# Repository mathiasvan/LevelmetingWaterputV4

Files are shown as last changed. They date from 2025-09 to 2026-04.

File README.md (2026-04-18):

# Levelmeting Waterput V4

## Description

This project is V4 in the levelmeting waterput project. It uses the [QDY30A level sensor with RS485 protocol](https://nl.aliexpress.com/item/1005004940352922.html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) because all the previous sensors broke.

This project uses the [ModbusMaster library](https://github.com/4-20ma/ModbusMaster/tree/master) which can be installed from the Library Manager in the Arduino IDE.

## Components

- Sensor is the [QDY30A level sensor with RS485 protocol](https://nl.aliexpress.com/item/1005004940352922.html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).
- [MAX485 module](https://nl.aliexpress.com/item/1005009235324836.html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) so that the Arduino/ESP32 can communicate with the modbus protocol by using the RX and TX pins.
- AZDelivery ESP32 Dev Kit C V4 for wireless data transmission which I had lying around.
- [220-240V to 24V power adapter](https://www.amazon.com.be/-/en/Universal-Adapter-220-240V-Inverter-Converter/dp/B0DRP7CS6Y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) as the sensor works on 24V.
- [24V to 5V step-down converter](https://www.amazon.com.be/-/en/Heemol-Converter-Module-DC-DC-Power/dp/B0BCV6GRH5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) to power the ESP32. The MAX485 module is powered by the 5V pin of the ESP32.

## Diagram

Thanks lejmr for this diagram. I used it to test my sensor. It is wrong for the TX and RX pins, they should be swapped. (See below for more.) The rest is the same as in this diagram.
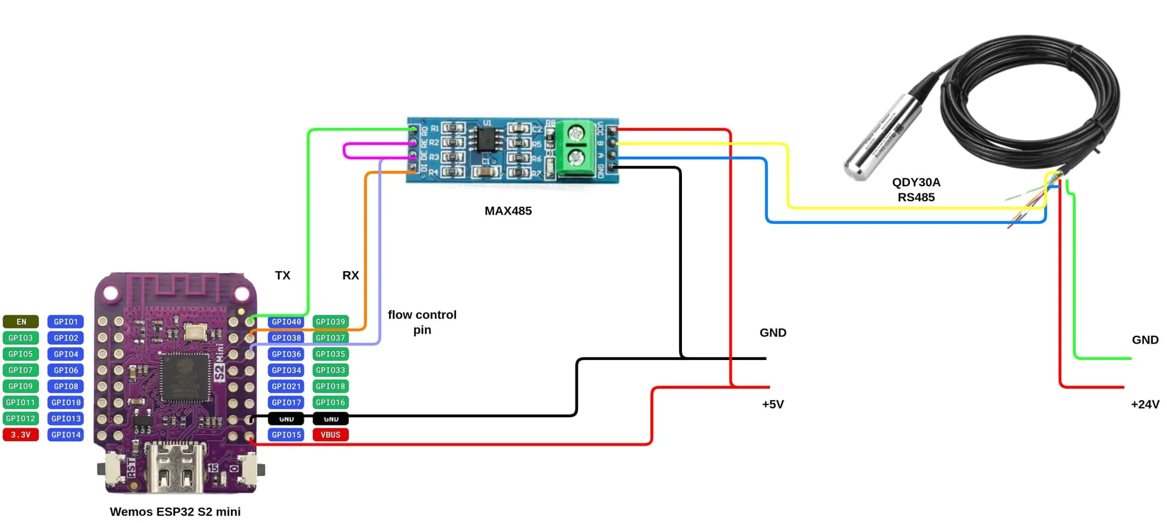
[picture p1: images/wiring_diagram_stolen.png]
Wiring diagram


My adaptation:
I used pin 2 on the ESP32 to connect the DE and RE pins from the MAX485 module.

See the final KiCad diagram under the `waterputv4Schematics` folder. Here is a screenshot in case you don't have KiCad.
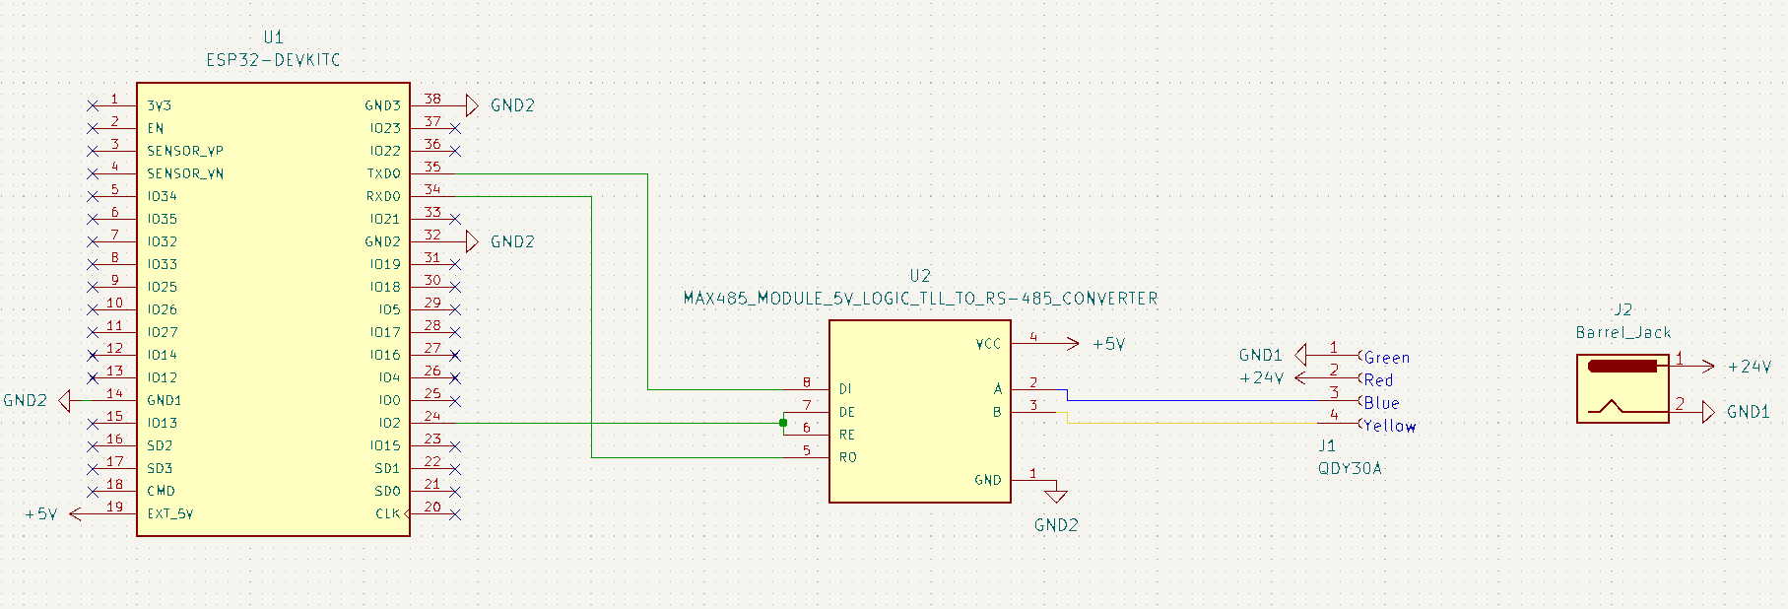
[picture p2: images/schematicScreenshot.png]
The final diagram


## Testing the sensor

This took a lot of trial and error but I got it working in the end. Some important remarks:

1. R0 from the MAX485 module should be connected to RX on the ESP32 and DI to TX. This is wrong in the original diagram I used.
2. The provided screw terminals on the MAX485 module are useful to connect the sensor to.
3. You cannot use the Serial port for debugging as you need the TX and RX pins to communicate with the sensor. I used the Bluetooth Serial library instead. You need to download the Bluetooth Serial app on your phone to connect to the wireless Serial.
4. When uploading the code, disconnect TX, RX, 5V and GND from the MAX485 and ESP32.
5. The test code is in the folder `testcode`.

## Final integration

- I have been using ThingSpeak for all the previous versions and it works quite well to store the data.
- The Bluetooth Serial library took too much space, so I have switched to the TelnetStream library. You need to install PuTTY and enter the IP adress which can be obtained from the Serial monitor. After this, it connects to the modbus sensor and from that moment on, all logging will happen with the telnet stream on PuTTY.
- You need to add a `credentials.h` file in the same folder as the final code. You need to fill this template with your own credentials.

```c++
#define mySSID "xxxxx"
#define myPASSWORD "xxxxx"
#define myChannelNumber 111111
#define myWriteAPIKey "xxxxxx"
```

## Telnet Commands

After connecting to your ESP32 using PuTTY (see IP address in Serial Monitor), you can use the following commands in the telnet console:

- **ping**  
  The ESP32 will respond with `pong`, show the current sensor height, and display the time remaining until the next automatic data upload to ThingSpeak.

- **send data**  
  Immediately triggers a sensor reading and uploads the value to ThingSpeak, regardless of the regular upload interval.

**Example session:**

```
> ping
pong
Doing a height reading...
Data at adress 4: 158
Converted height: 15.8cm
15.80
Time to next data send: 122 seconds

> send data
Sending data now...
Data at adress 4: 158
Converted height: 15.8cm
Height: 15.8cm
Uploading data to ThingSpeak...
Successful upload to ThingSpeak.
Height: 15.80 uploaded to ThingSpeak server.

```

If you enter an unknown command, nothing will happen. Commands are case-sensitive.

**Tip:**  
Make sure you have connected to the correct IP address and that your ESP32 is powered and connected to WiFi.

## Wishlist

- [ ] Add `reconnect wifi` command.
- [ ] OTA updates

## Resources

- [Datasheets that came in the box](https://h5.hlcode.com.cn/?id=NK1LFtJ&f=wx)
- [Thanks a lot to lejmr for this project!](https://github.com/lejmr/dyi-ha-water-management)
- [This tutorial has helped me a lot](https://how2electronics.com/how-to-use-modbus-rtu-with-esp32-to-read-sensor-data/)

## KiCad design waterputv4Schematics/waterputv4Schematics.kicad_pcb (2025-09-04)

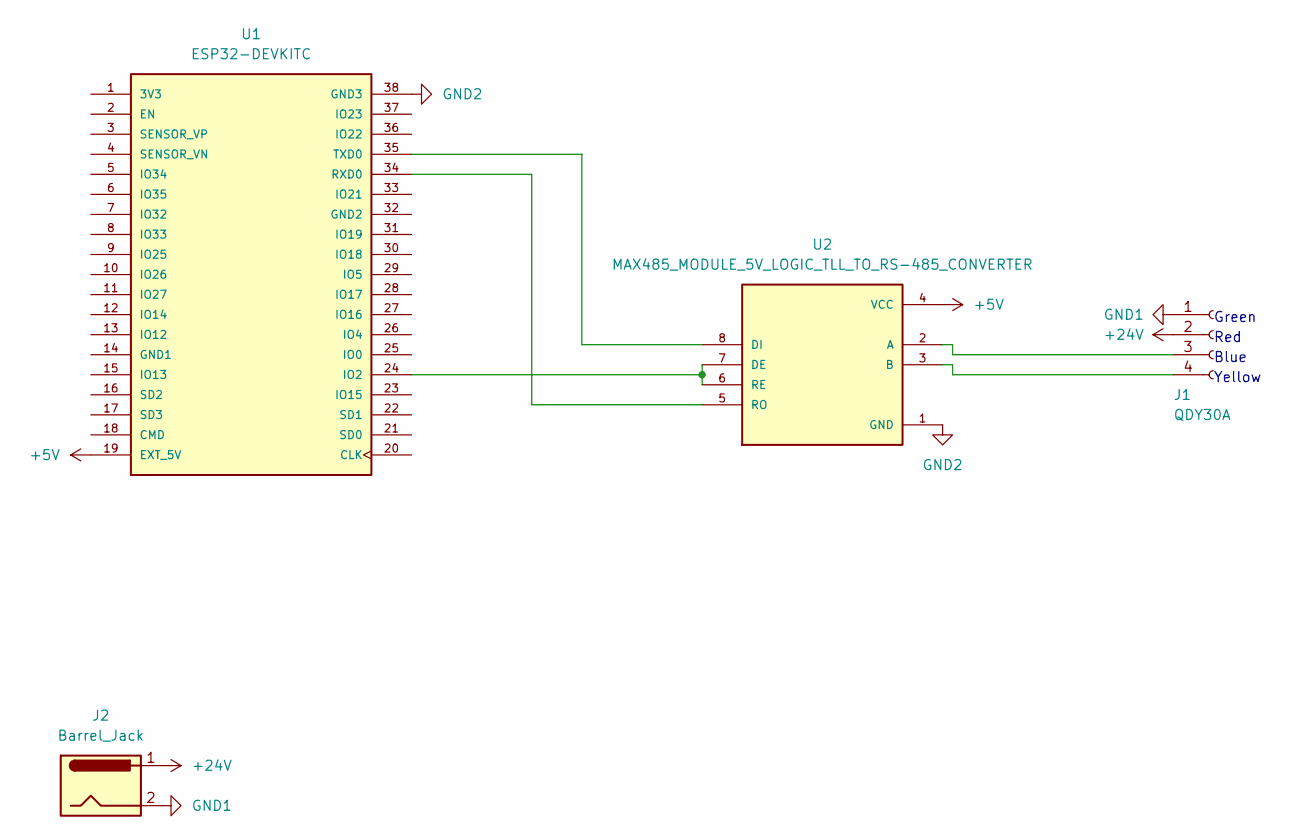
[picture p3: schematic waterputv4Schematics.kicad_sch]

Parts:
J1: QDY30A
J2: Barrel_Jack; BarrelJack_Horizontal
U1: ESP32-DEVKITC; MODULE_ESP32-DEVKITC; PARTREV N/A
U2: MAX485_MODULE_5V_LOGIC_TLL_TO_RS-485_CONVERTER; MODULE_MAX485_MODULE_5V_LOGIC_TLL_TO_RS-485_CONVERTER; PARTREV 1r0

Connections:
+5V: U1.19 (EXT_5V), U2.4 (VCC)
+24V: J1.2, J2.1
GND1: J1.1, J2.2
GND2: U1.38 (GND3), U2.1 (GND)
unnamed: U1.24 (IO2), U2.6 (RE), U2.7 (DE)
unnamed: U1.34 (RXD0), U2.5 (RO)
unnamed: U1.35 (TXD0), U2.8 (DI)
unnamed: J1.3, U2.2 (A)
unnamed: J1.4, U2.3 (B)

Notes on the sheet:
Red
Blue
Yellow
Green

Board: 2 copper layers, 4 parts (0 on the bottom side), 9 nets, no tracks yet.

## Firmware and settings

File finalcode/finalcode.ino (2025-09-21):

/*

    Reads the value of a QDY30A level sensor and sends the data to ThingSpeak.

    Check the logs of the sensor with a telnet client (PuTTY). Commands:
    - ping: the esp32 will respond with pong and the current height
    - send data: immediately sends data to ThingSpeak, instead of waiting for the next interval
    Last IP adress = 192.168.1.57 (can change, see Serial communication if last IP adress does not work)

    Mathias Van Nuland 2025
    Last updated on 21/09/2025

*/


#include <credentials.h>   // Credentials that are not uploaded to GitHub
#include <WiFi.h>          // Wifi library
#include <ThingSpeak.h>    // Communicating with ThingSpeak
#include <ModbusMaster.h>  // Communicate with the Modbus RS485 protocol https://github.com/4-20ma/ModbusMaster/tree/master
#include <TelnetStream.h>  // Use PuTTY to view the logs, last IP adress = 192.168.1.57

/* -------------------- SENSOR -------------------- */

#define FLOWCONTROLPIN 2  // RE and DE pins on MAX485

ModbusMaster node;  // Create Modbus object

// What should happen before transmission
void preTransmission() {
    digitalWrite(FLOWCONTROLPIN, HIGH);  // Enable writing
}

// What should happen after transmission
void postTransmission() {
    digitalWrite(FLOWCONTROLPIN, LOW);  // Enable reading
}

/* -------------------- WIFI AND THINGSPEAK -------------------- */

WiFiClient client;

// Replace with your network credentials (STATION)
const char* ssid = mySSID;
const char* password = myPASSWORD;

// Keep track when connected (or not) to the WiFi
const unsigned long CHECK_WIFI_INTERVAL = 15000;
unsigned long WiFiPreviousMillis = 0;

// ThingSpeak sends a code to say if the upload was successful or not.
int thingSpeakStatus;
unsigned long channelNumber = myChannelNumber;  // Channel number of my thingSpeak fields.
const char* writeAPIKey = myWriteAPIKey;        // ThingSpeak write API key

// Keep track of when last data sent to ThingSpeak
const unsigned long SEND_DATA_INTERVAL = 3 * 1000 * 60;  // 3 min
unsigned long dataPreviousMillis = -SEND_DATA_INTERVAL;  // Send distance on startup for quick testing

void initWiFi() {
    WiFi.mode(WIFI_STA);
    WiFi.begin(ssid, password);
    Serial.print("Connecting to WiFi...");
    while (WiFi.status() != WL_CONNECTED) {
        Serial.print('.');
        delay(500);
    }
    Serial.print('\n');
    Serial.print("IP address: ");
    Serial.println(WiFi.localIP());
}

void reconnectToWiFi() {
    TelnetStream.println("Disconnecting WiFi...");
    WiFi.disconnect();
    TelnetStream.println("Reconnecting to WiFi...");
    WiFi.reconnect();
    TelnetStream.println("Reconnected to WiFi.");
}

// Gets the height from the sensor. -1.0 is error
float getHeight() {
    uint8_t result;  // Result error/success codes
    uint16_t data;   // Sensor data
    float height = -1.0;

    // Read one register, starting from 0x0004
    result = node.readHoldingRegisters(0x0004, 1);

    if (result == node.ku8MBSuccess) {  // Successfully read data
        data = node.getResponseBuffer(0x00);
        height = data / 10.0;  // convert to cm

        TelnetStream.print("Data at adress ");
        TelnetStream.print(0x0004);
        TelnetStream.print(": ");
        TelnetStream.println(data);  // Print the raw data

        TelnetStream.print("Converted height: ");
        TelnetStream.print(height, 1);  // Print the height in cm with one digit after the decimal point, as is defined in the datasheet
        TelnetStream.println("cm");
    } else {  // Some kind of error happened.
        if (result == node.ku8MBInvalidSlaveID) {
            TelnetStream.println("Invalid slave ID.");
        } else if (result == node.ku8MBInvalidFunction) {
            TelnetStream.println("Invalid Modbus function code.");
        } else if (result == node.ku8MBResponseTimedOut) {
            TelnetStream.println("Sensor response timed out.");
        } else if (result == node.ku8MBInvalidCRC) {
            TelnetStream.println("Invalid CRC.");
        } else {
            TelnetStream.println("Unknown sensor error.");
        }
    }

    return height;
}

bool sendHeight(float h) {
    // Preparing to upload data to ThingSpeak
    TelnetStream.println("Uploading data to ThingSpeak...");
    ThingSpeak.setField(1, h);

    // Upload data to ThingSpeak
    thingSpeakStatus = ThingSpeak.writeFields(channelNumber, writeAPIKey);

    // Handle thingSpeak errors. For more information: visit https://github.com/mathworks/thingspeak-arduino
    if (thingSpeakStatus == 200) {
        TelnetStream.println("Successful upload to ThingSpeak.");
        return true;
    } else {
        TelnetStream.print("Error updating ThingSpeak channels. Error code: ");
        TelnetStream.println(thingSpeakStatus);
        if (thingSpeakStatus == -301) {
            TelnetStream.println("Failed to connect to ThingSpeak.");
        } else if (thingSpeakStatus == -302) {
            TelnetStream.println("Unexpected failure during write to ThingSpeak.");
        } else if (thingSpeakStatus == -303) {
            TelnetStream.println("Unable to parse response.");
        } else if (thingSpeakStatus == -304) {
            TelnetStream.println("Timeout waiting for server to respond.");
        } else if (thingSpeakStatus == -401) {
            TelnetStream.println("Point was not inserted (most probable cause is the rate limit of once every 15 seconds).");
        } else if (thingSpeakStatus == 400) {
            TelnetStream.println("Error: thingSpeakStatus == 400");
        } else {
            TelnetStream.println("Unknown error.");
        }
        return false;
    }
}

// Sends the height to ThingSpeak, handles errors and reconnects to WiFi if needed
void sendData() {
    float height = getHeight();  // Get height from sensor
    TelnetStream.print("Height: ");
    TelnetStream.print(height, 1);
    TelnetStream.println("cm");

    if (height > 200.0) {  // Sensor is dry
        TelnetStream.println("Height > 200.0");
        TelnetStream.println("Dry sensor, changing height to 0...");
        height = 0;
    }

    if (height == -1.0) {  // Sensor error. Check wiring!
        TelnetStream.println("Height == -1.0");
        TelnetStream.println("Not attempting upload to ThingSpeak due to error with sensor. Check wiring!");
    } else {
        // Try to send distance to thingspeak, else reconnect to WiFi
        if (sendHeight(height)) {
            TelnetStream.print("Height: ");
            TelnetStream.print(height);
            TelnetStream.println(" uploaded to ThingSpeak server.");
        } else {  // Reconnect to WiFi
            TelnetStream.println("Sending data to ThingSpeak servers failed. Reconnecting to WiFi...");
            reconnectToWiFi();
        }
    }
}

/* -------------------- SETUP -------------------- */

void setup() {
    pinMode(FLOWCONTROLPIN, OUTPUT);    // RE and DE pins on MAX485
    digitalWrite(FLOWCONTROLPIN, LOW);  // Start in listening mode so that setup Serial prints do not interfere with the sensor

    Serial.begin(9600);                       // Communication with Modbus sensor (baudrate from datasheet) and print ip adress of esp32 for logging with PuTTY later
    node.begin(1, Serial);                    // Start Modbus sensor with adress 1
    node.preTransmission(preTransmission);    // Ensure the FLOWCONTROL pin is correct for transmission
    node.postTransmission(postTransmission);  // Ensure the FLOWCONTROL pin is correct for receiving

    // Connect to WiFi
    initWiFi();

    // Start logging, connect with PuTTY to the ip adress
    TelnetStream.begin();

    // Start the thingSpeak object.
    ThingSpeak.begin(client);
    TelnetStream.println("Started ThingSpeak object.");

    TelnetStream.println("End setup.");
}

/* -------------------- LOOP -------------------- */

void loop() {
    // if WiFi is down, try reconnecting every CHECK_WIFI_INTERVAL milliseconds
    unsigned long currentMillis = millis();
    if ((WiFi.status() != WL_CONNECTED) && (currentMillis - WiFiPreviousMillis >= CHECK_WIFI_INTERVAL)) {
        WiFiPreviousMillis = currentMillis;
        TelnetStream.print("Connection lost. Current millis: ");
        TelnetStream.println(currentMillis);
        TelnetStream.println("Reconnecting to WiFi...");
        reconnectToWiFi();
    }

    // Only send data every SEND_DATA_INTERVAL milliseconds
    currentMillis = millis();
    if (WiFi.status() == WL_CONNECTED && (currentMillis - dataPreviousMillis >= SEND_DATA_INTERVAL)) {
        dataPreviousMillis = currentMillis;
        sendData();
    }

    // Handle telnet commands
    String buffer = "";
    while (TelnetStream.available()) {
        buffer += (char)TelnetStream.read();
    }

    buffer.trim();  // Remove any leading/trailing whitespace

    if (buffer == "ping") {  // If the user types "ping" in the telnet console, the esp32 will respond with "pong"
        TelnetStream.println("pong");
        TelnetStream.println("Doing a height reading...");
        TelnetStream.println(getHeight());
        TelnetStream.print("Time to next data send: ");
        TelnetStream.print((SEND_DATA_INTERVAL - (millis() - dataPreviousMillis)) / 1000);
        TelnetStream.println(" seconds");
    } else if (buffer == "send data") {
        TelnetStream.println("Sending data now...");
        dataPreviousMillis = currentMillis;
        sendData();
    }
}

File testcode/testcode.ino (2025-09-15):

#include <ModbusMaster.h>     // Communicate with the Modbus RS485 protocol
#include <BluetoothSerial.h>  // Use the "Serial Bluetooth" app to view the serial output

#define FLOWCONTROLPIN 2  // RE and DE pins on MAX485

ModbusMaster node;  // Create Modbus object

// What should happen before transmission
void preTransmission() {
    digitalWrite(FLOWCONTROLPIN, HIGH);  // Enable writing
}

// What should happen after transmission
void postTransmission() {
    digitalWrite(FLOWCONTROLPIN, LOW);  // Enable reading
}

String device_name = "LogWaterput";  // Connect to this Bluetooth device on your phone

// Check if Bluetooth is available
#if !defined(CONFIG_BT_ENABLED) || !defined(CONFIG_BLUEDROID_ENABLED)
#error Bluetooth is not enabled! Please run `make menuconfig` to and enable it
#endif

// Check Serial Port Profile
#if !defined(CONFIG_BT_SPP_ENABLED)
#error Serial Port Profile for Bluetooth is not available or not enabled. It is only available for the ESP32 chip.
#endif

// Create BluetoothSerial object
BluetoothSerial SerialBT;

void setup() {
    pinMode(FLOWCONTROLPIN, OUTPUT);
    digitalWrite(FLOWCONTROLPIN, LOW);  // Start in listening mode

    Serial.begin(9600);  // Communication with Modbus sensor

    node.begin(1, Serial);                    // Start Modbus sensor with adress 1
    node.preTransmission(preTransmission);    // Ensure the FLOWCONTROl pin is correct for transmission
    node.postTransmission(postTransmission);  // Ensure the FLOWCONTROl pin is correct for receiving

    SerialBT.begin(device_name);  // Bluetooth device name
                                  // SerialBT.deleteAllBondedDevices(); // Uncomment this to delete paired devices; Must be called after begin
}

void loop() {
    uint8_t result;  // Result error/success codes
    uint16_t data;

    // Read one register, starting from 0x0004
    result = node.readHoldingRegisters(0x0004, 1);

    if (result == node.ku8MBSuccess) {
        data = node.getResponseBuffer(0x00);
        SerialBT.print("Data at adress ");
        SerialBT.print(0x0004, HEX);
        SerialBT.print(": ");
        SerialBT.print(data / 10.0f, 1);  // Print the data in cm with one digit after the decimal point, as is defined in the datasheet
        SerialBT.println("cm");
    } else {  // Some kind of error happened.
        if (result == node.ku8MBInvalidSlaveID) {
            SerialBT.println("Invalid slave ID.");
        } else if (result == node.ku8MBInvalidFunction) {
            SerialBT.println("Invalid Modbus function code.");
        } else if (result == node.ku8MBResponseTimedOut) {
            SerialBT.println("Response timed out.");
        } else if (result == node.ku8MBInvalidCRC) {
            SerialBT.println("Invalid CRC.");
        } else {
            SerialBT.println("Unknown error.");
        }
    }

    delay(2000);
}

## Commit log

2025-09-04 Testcode and first diagram complete
    [waterputv4Schematics.kicad_pcb, waterputv4Schematics.kicad_sch]
2025-09-15 Final code
    [waterputv4Schematics.kicad_sch]
2025-09-15 Fix for screenshot of schematic image readme
2025-09-15 Actual fix of screenshot of schematic readme
2025-09-16 Fix for unkown command bug
    [finalcode.ino]
2025-09-16 Improved documentation and small fixes
    [finalcode.ino]
